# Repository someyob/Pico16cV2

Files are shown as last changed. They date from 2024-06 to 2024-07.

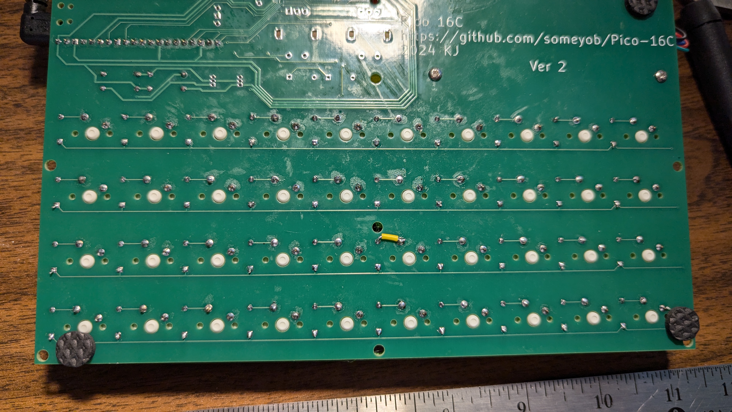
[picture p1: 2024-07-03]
pictures/bodge installed.jpg

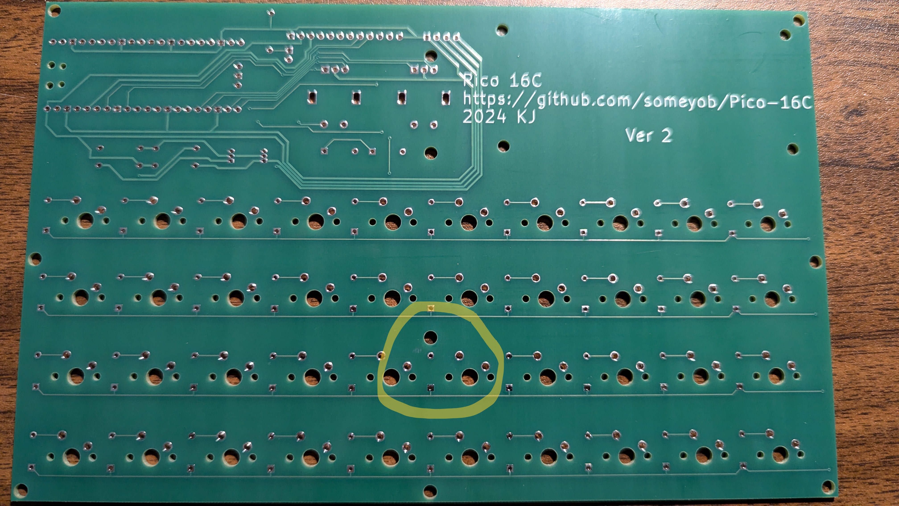
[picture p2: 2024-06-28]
pictures/bottom w. bodge.jpg

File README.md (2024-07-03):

# Pico16cV2

I've always wanted an HP 16C calculator, the gold standard for early programmers.  In those years, I was too poor, needed to focus on Scientific Calculators in university.  These days, prices are crazy on the used market.

While newer incarnations existed, (e.g. SwissMicro https://www.swissmicros.com/product/dm16l) looked great, they did't scratch my other itches, which were to play with microcontrollers and learn a new language (python).  The primary use for the thing will be (and is now) as a tool to help with the design and assembly language programming of a 6502-based computer.  This computer is based off of the Ben Eater instructional videos, which I highly recommend.

The prototype was done with cheap aliexpress parts and prototoboard, and can be seen here:  https://github.com/someyob/Pico-16C

Because I wasn't happy with the keypads (primarily), and hoped to make a more professional version, I did up a citcuit in KiCAD and sent away to have the PCBs done at PCBway.  (the build was sponsored by PCBway, and my thoughts on the product and the company will be posted on my Hackaday.io page).

The original prototype and version 2 getting assembled:



I used brown keyswitches with transparent 2-piece keycaps to create the keyboard, a standard i2c 1602 lcd display (2 lines of 16 characters), and a Raspberry Pi Pico.  The coding is done in CircuitPython.  The result is much bigger than a real 16C, but that wasn't a huge impediment for me.  The biggest challenge, aside from coding, was to make the keycaps look good.  I think it's an improvement over the prototype.

The fully assembled v2 is shown here:

v2 pic 1
v2 pic 2

At this point, lots of extra functionality still has to go in here, but it does the basic stuff, and in the same fashion as the true 16C (using RPN).

You may note that there's some unpopulated components on the PCB.  In order to take advantage of the space, and create other optional capabilities, I added two rotary encoders and included them (each includes a push-button) in the keypad matrix.  This way, I can use the same pcb as a basis for a macro keyboard.  There's also breakouts of the unused Pi Pico GPIO as well as a spot for an LED, should it find a use.

More notes on the build and the software to come.

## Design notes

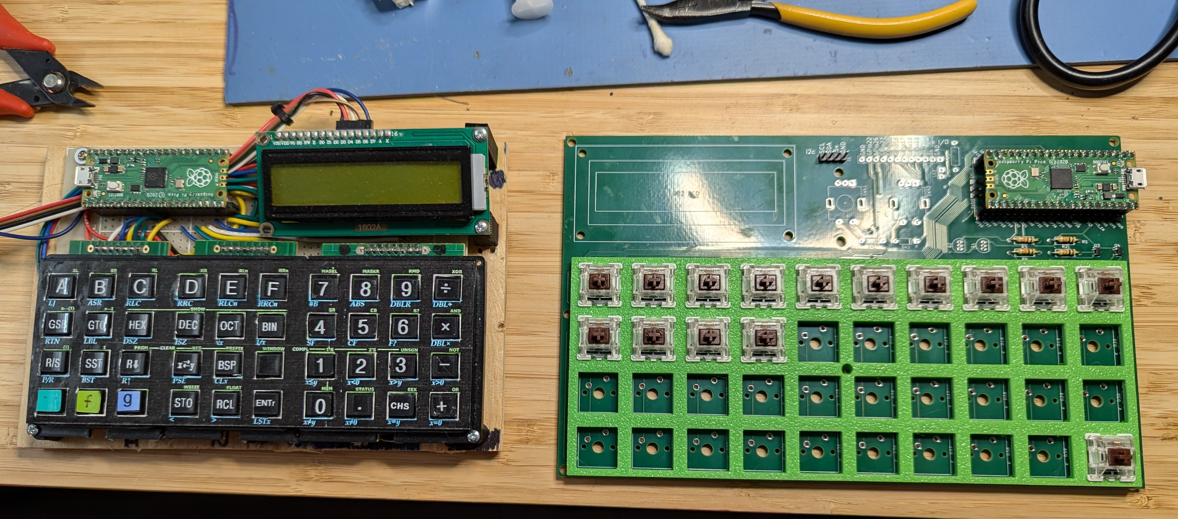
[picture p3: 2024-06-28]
pictures/prototype and v2.jpg

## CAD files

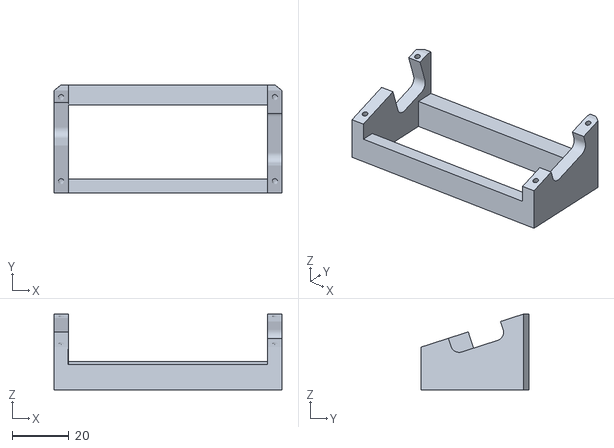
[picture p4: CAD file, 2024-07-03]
3dparts/displaybracket.stl
80.0 x 38.0 x 26.6

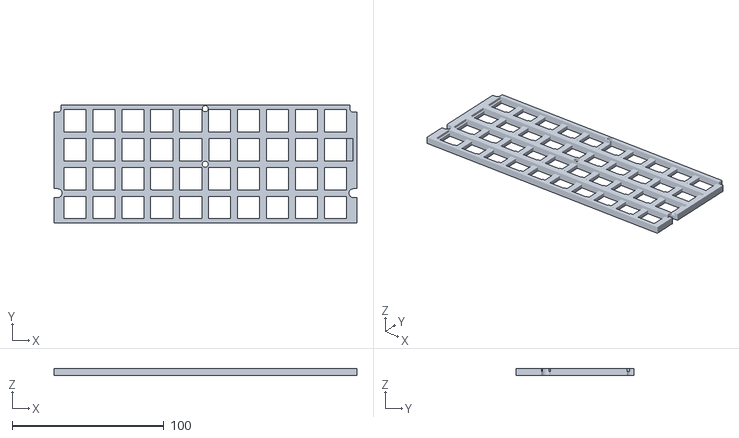
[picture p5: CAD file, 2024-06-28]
3dparts/keypad.stl
199.9 x 77.6 x 4.80

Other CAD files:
3dparts/displaybracket.skp
3dparts/keypad.skp

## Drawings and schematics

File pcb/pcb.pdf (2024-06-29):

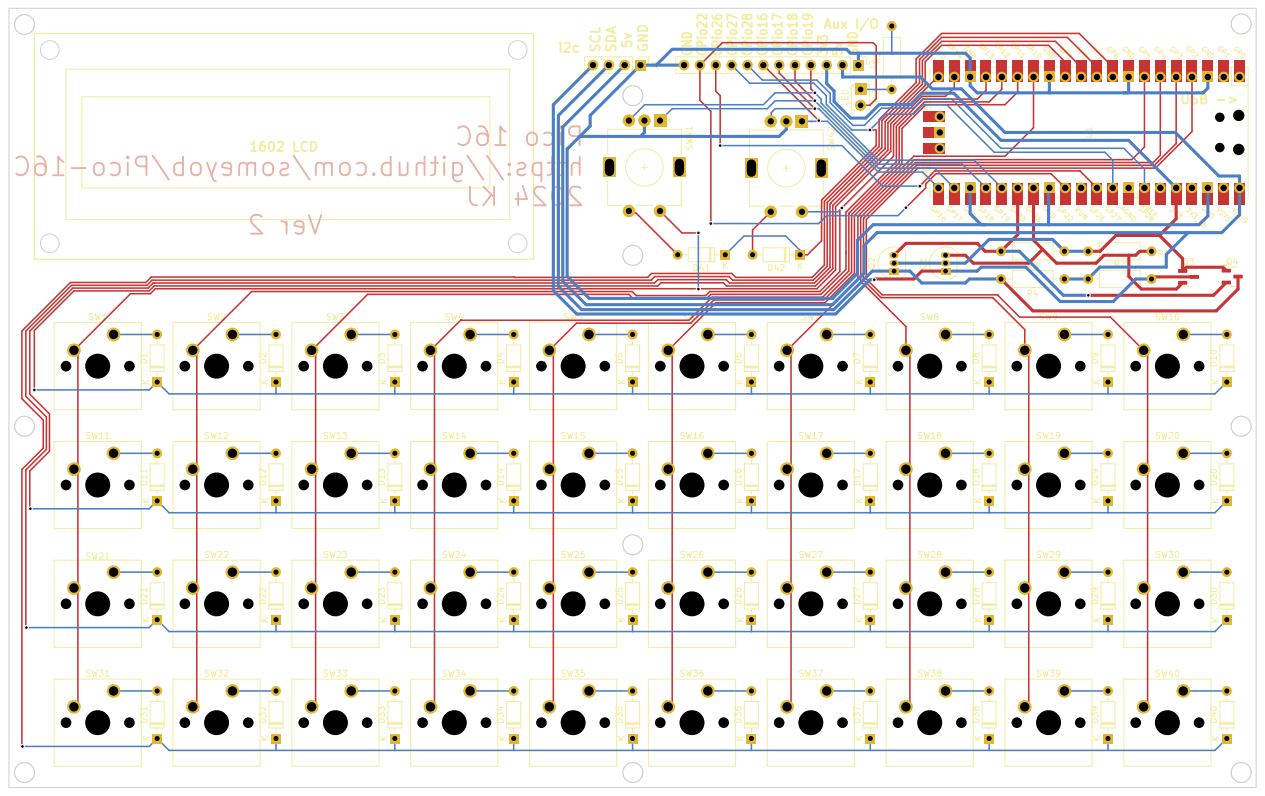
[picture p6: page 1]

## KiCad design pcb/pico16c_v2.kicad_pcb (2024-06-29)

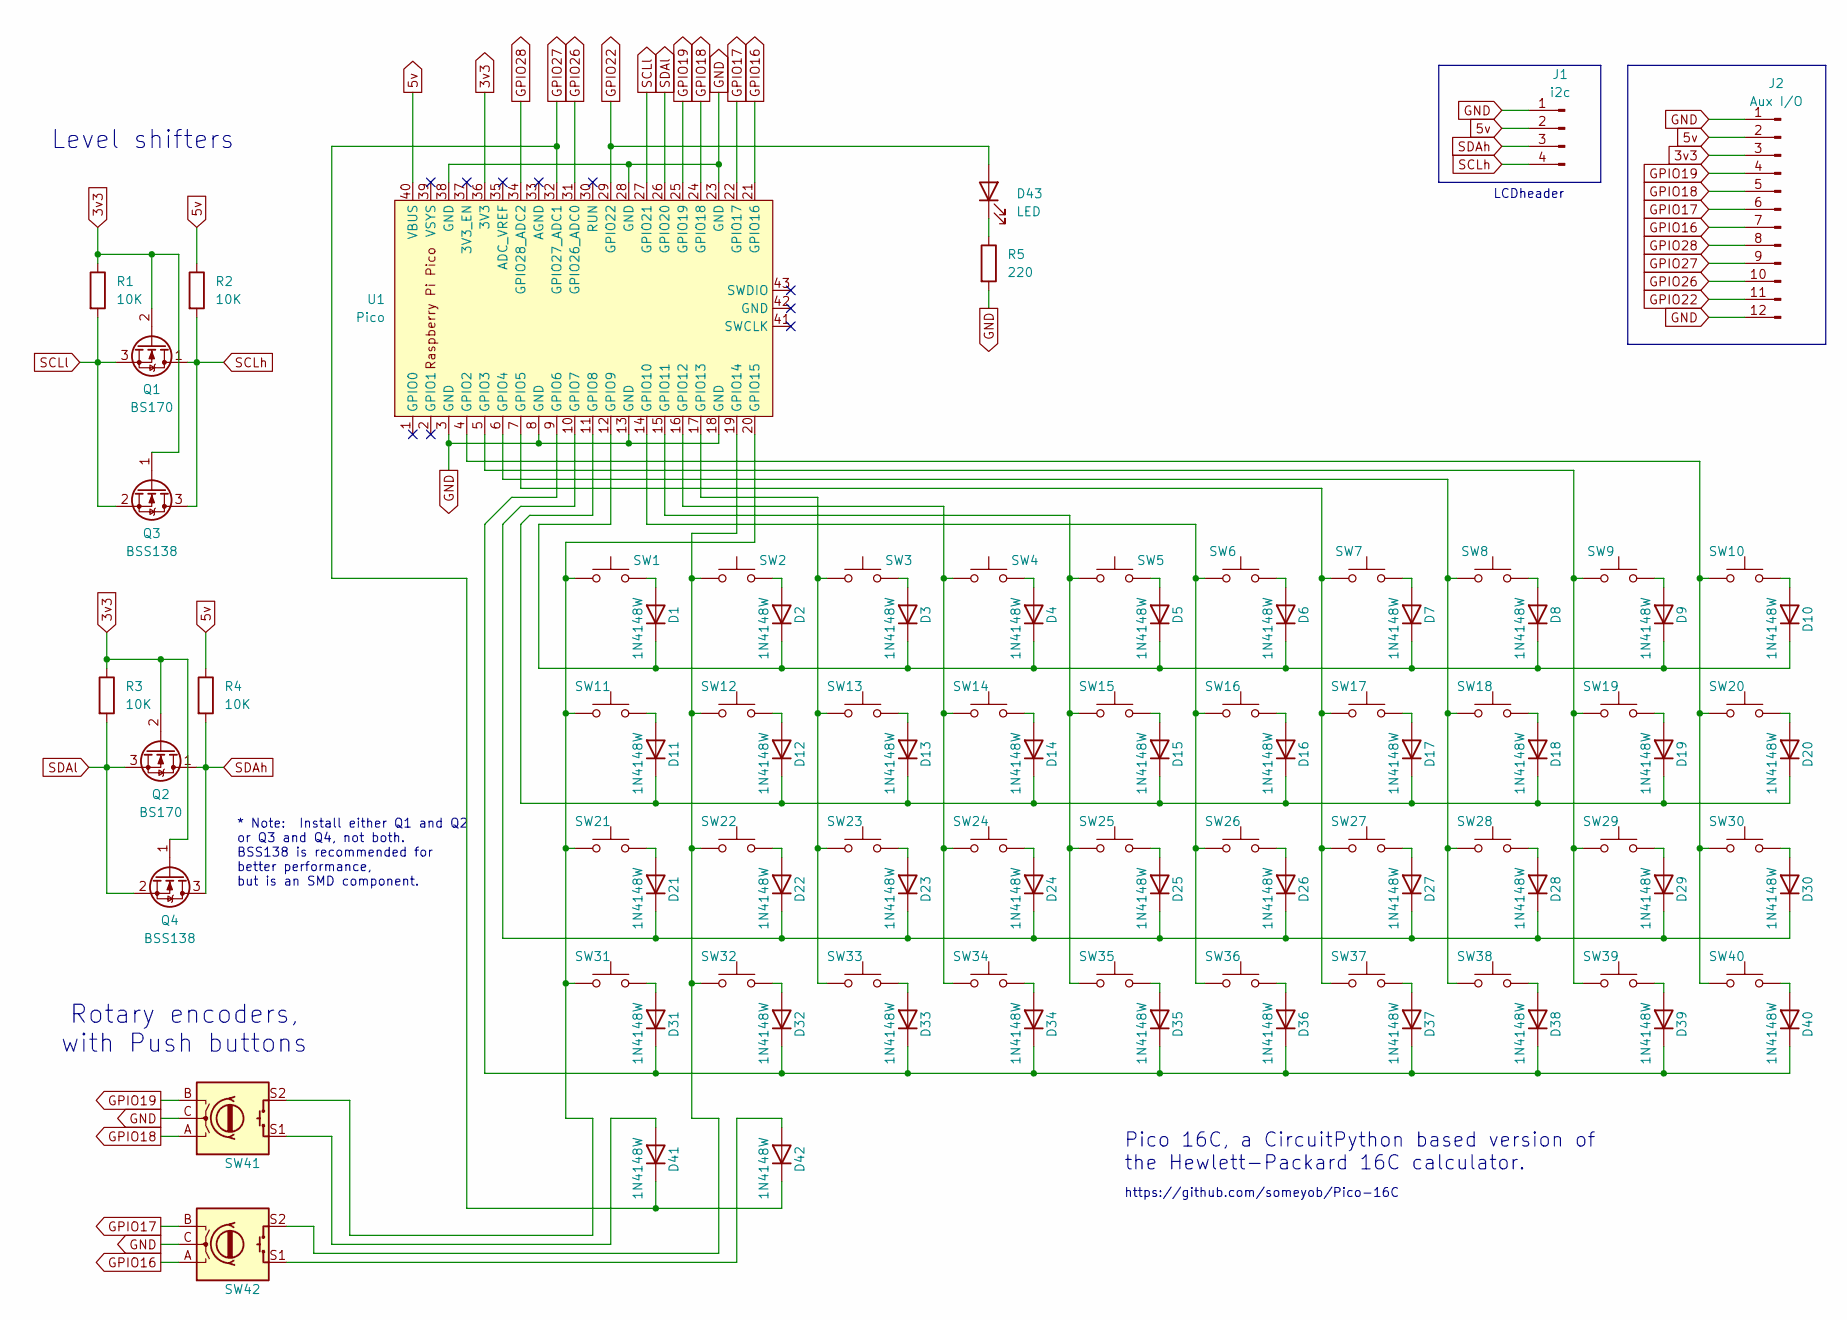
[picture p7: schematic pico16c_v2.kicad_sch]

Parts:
D1, D2, D3, D4, D5, D6, D7, D8, D9, D10, D11, D12, D13, D14, D15, D16, D17, D18, D19, D20, D21, D22, D23, D24, D25, D26, D27, D28, D29, D30, D31, D32, D33, D34, D35, D36, D37, D38, D39, D40, D41, D42: 1N4148W; D_DO-35_SOD27_P7.62mm_Horizontal
D43: LED; LED_D2.0mm_W4.0mm_H2.8mm_FlatTop
J1: i2c; PinHeader_1x04_P2.54mm_Vertical
J2: Aux I/O; PinHeader_1x12_P2.54mm_Vertical
Q1, Q2: BS170; TO-92_Inline
Q3, Q4: BSS138; SOT-23
R1, R2, R3, R4: 10K; R_Axial_DIN0207_L6.3mm_D2.5mm_P10.16mm_Horizontal
R5: 220; R_Axial_DIN0207_L6.3mm_D2.5mm_P10.16mm_Horizontal
SW1, SW2, SW3, SW4, SW5, SW6, SW7, SW8, SW9, SW10, SW11, SW12, SW13, SW14, SW15, SW16, SW17, SW18, SW19, SW20, SW21, SW22, SW23, SW24, SW25, SW26, SW27, SW28, SW29, SW30, SW31, SW32, SW33, SW34, SW35, SW36, SW37, SW38, SW39, SW40: SW_Push; SW_Cherry_MX_1.00u_PCB
SW41, SW42: Encoder_Switch; RotaryEncoder_Alps_EC11E-Switch_Vertical_H20mm
U1: Pico; RPi_Pico_SMD_TH

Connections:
3v3: J2.3, Q1.2 (G), Q2.2 (G), Q3.1 (G), Q4.1 (G), R1.1, R3.1, U1.36 (3V3)
5v: J1.2, J2.2, R2.1, R4.1, U1.40 (VBUS)
GND: J1.1, J2.1, J2.12, R5.2, SW41.C, SW42.C, U1.3 (GND), U1.8 (GND), U1.13 (GND), U1.18 (GND), U1.23 (GND), U1.28 (GND), U1.38 (GND)
GPIO16: J2.7, SW42.A, U1.21 (GPIO16)
GPIO17: J2.6, SW42.B, U1.22 (GPIO17)
GPIO18: J2.5, SW41.A, U1.24 (GPIO18)
GPIO19: J2.4, SW41.B, U1.25 (GPIO19)
GPIO22: D43.2 (A), J2.11, U1.29 (GPIO22)
GPIO26: J2.10, U1.31 (GPIO26_ADC0)
GPIO27: D41.1 (K), D42.1 (K), J2.9, U1.32 (GPIO27_ADC1)
GPIO28: J2.8, U1.34 (GPIO28_ADC2)
unnamed: D1.2 (A), SW1.1
unnamed: D1.1 (K), D2.1 (K), D3.1 (K), D4.1 (K), D5.1 (K), D6.1 (K), D7.1 (K), D8.1 (K), D9.1 (K), D10.1 (K), U1.12 (GPIO9)
unnamed: D2.2 (A), SW2.1
unnamed: D3.2 (A), SW3.1
unnamed: D4.2 (A), SW4.1
unnamed: D5.2 (A), SW5.1
unnamed: D6.2 (A), SW6.1
unnamed: D7.2 (A), SW7.1
unnamed: D8.2 (A), SW8.1
unnamed: D9.2 (A), SW9.1
unnamed: D10.2 (A), SW10.1
unnamed: D11.2 (A), SW11.1
unnamed: D11.1 (K), D12.1 (K), D13.1 (K), D14.1 (K), D15.1 (K), D16.1 (K), D17.1 (K), D18.1 (K), D19.1 (K), D20.1 (K), U1.11 (GPIO8)
unnamed: D12.2 (A), SW12.1
unnamed: D13.2 (A), SW13.1
unnamed: D14.2 (A), SW14.1
unnamed: D15.2 (A), SW15.1
unnamed: D16.2 (A), SW16.1
unnamed: D17.2 (A), SW17.1
unnamed: D18.2 (A), SW18.1
unnamed: D19.2 (A), SW19.1
unnamed: D20.2 (A), SW20.1
unnamed: D21.2 (A), SW21.1
unnamed: D21.1 (K), D22.1 (K), D23.1 (K), D24.1 (K), D25.1 (K), D26.1 (K), D27.1 (K), D28.1 (K), D29.1 (K), D30.1 (K), U1.10 (GPIO7)
unnamed: D22.2 (A), SW22.1
unnamed: D23.2 (A), SW23.1
unnamed: D24.2 (A), SW24.1
unnamed: D25.2 (A), SW25.1
unnamed: D26.2 (A), SW26.1
unnamed: D27.2 (A), SW27.1
unnamed: D28.2 (A), SW28.1
unnamed: D29.2 (A), SW29.1
unnamed: D30.2 (A), SW30.1
unnamed: D31.2 (A), SW31.1
unnamed: D31.1 (K), D32.1 (K), D33.1 (K), D34.1 (K), D35.1 (K), D36.1 (K), D37.1 (K), D38.1 (K), D39.1 (K), D40.1 (K), U1.9 (GPIO6)
unnamed: D32.2 (A), SW32.1
unnamed: D33.2 (A), SW33.1
unnamed: D34.2 (A), SW34.1
unnamed: D35.2 (A), SW35.1
unnamed: D36.2 (A), SW36.1
unnamed: D37.2 (A), SW37.1
unnamed: D38.2 (A), SW38.1
unnamed: D39.2 (A), SW39.1
unnamed: D40.2 (A), SW40.1
unnamed: D41.2 (A), SW41.S1
unnamed: D42.2 (A), SW42.S1
unnamed: D43.1 (K), R5.1
unnamed: SW10.2, SW20.2, SW30.2, SW40.2, U1.4 (GPIO2)
unnamed: SW9.2, SW19.2, SW29.2, SW39.2, U1.5 (GPIO3)
unnamed: SW8.2, SW18.2, SW28.2, SW38.2, U1.6 (GPIO4)
unnamed: SW7.2, SW17.2, SW27.2, SW37.2, U1.7 (GPIO5)
unnamed: SW6.2, SW16.2, SW26.2, SW36.2, U1.14 (GPIO10)
unnamed: SW5.2, SW15.2, SW25.2, SW35.2, U1.15 (GPIO11)
unnamed: SW4.2, SW14.2, SW24.2, SW34.2, U1.16 (GPIO12)
unnamed: SW3.2, SW13.2, SW23.2, SW33.2, U1.17 (GPIO13)
unnamed: SW2.2, SW12.2, SW22.2, SW32.2, SW42.S2, U1.19 (GPIO14)
unnamed: SW1.2, SW11.2, SW21.2, SW31.2, SW41.S2, U1.20 (GPIO15)
SCLh: J1.4, Q1.1 (D), Q3.3 (D), R2.2
SCLl: Q1.3 (S), Q3.2 (S), R1.2, U1.27 (GPIO21)
SDAh: J1.3, Q2.1 (D), Q4.3 (D), R4.2
SDAl: Q2.3 (S), Q4.2 (S), R3.2, U1.26 (GPIO20)

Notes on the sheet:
Pico 16C, a CircuitPython based version of the Hewlett-Packard 16C calculator.
https://github.com/someyob/Pico-16C
LCDheader
* Note: Install either Q1 and Q2 or Q3 and Q4, not both. BSS138 is recommended for better performance, but is an SMD component.
Rotary encoders, with Push buttons
Level shifters

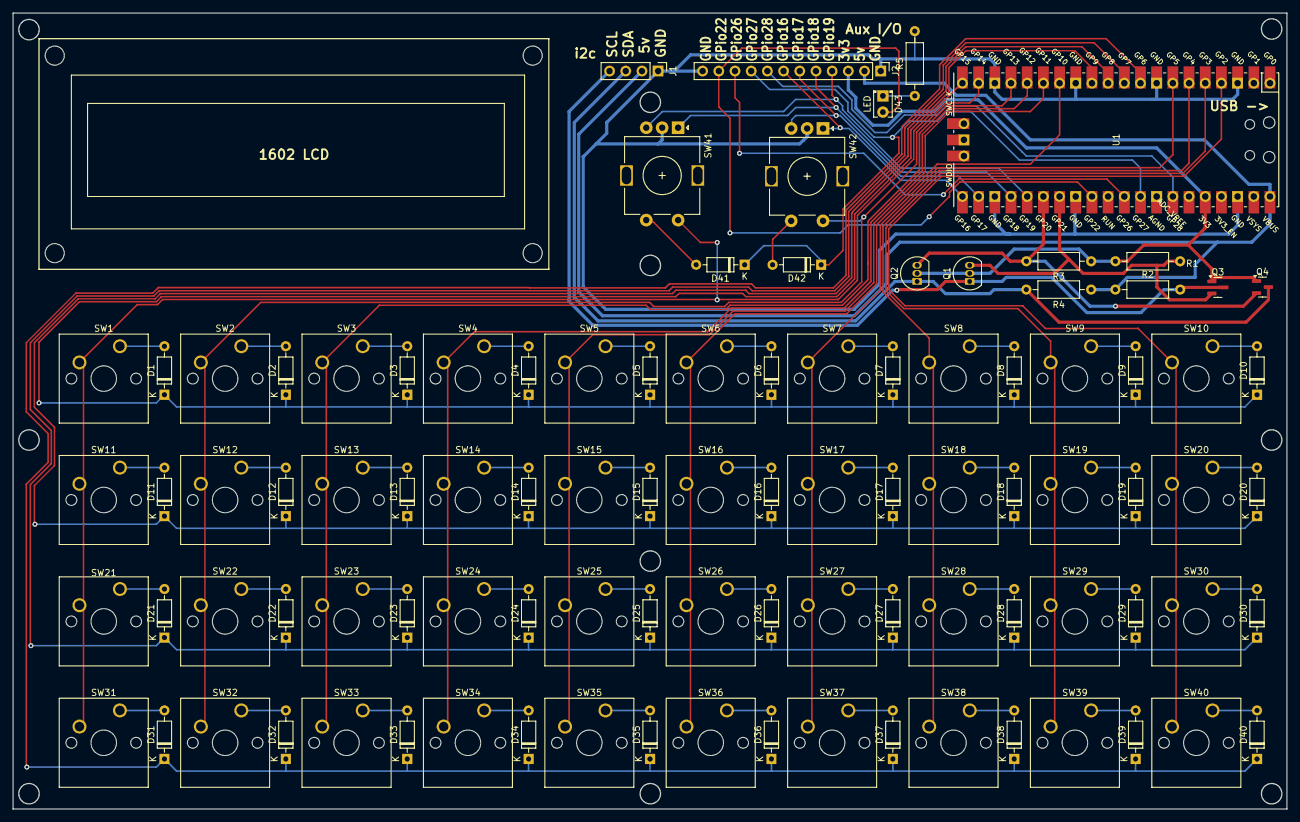
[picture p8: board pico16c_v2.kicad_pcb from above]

Board: 2 copper layers, 199.9 x 124.9 mm, 97 parts (0 on the bottom side), 72 nets.

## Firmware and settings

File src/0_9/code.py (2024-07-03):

# Use
# https://learn.adafruit.com/keep-your-circuitpython-libraries-on-devices-up-to-date-with-circup/usage
# 'circup' to manage packages on this device
# eg 'circup install adafruit_debouncer'

import time
import board
import busio
from time import sleep, monotonic
from circuitpython_i2c_lcd import I2cLcd
from PICO_16C_keypad import *

from digitalio import DigitalInOut, Pull

import keypad

version_string = "Pico 16C v0.9"
release_string = "29 Jun 2024   KJ"

#### Display init
i2c = busio.I2C(board.GP21, board.GP20)   # SCL, SDA
# circuitpython seems to require locking the i2c bus
while i2c.try_lock():
    pass

DEFAULT_I2C_ADDR = 0x27
lcd = I2cLcd(i2c, DEFAULT_I2C_ADDR, 2, 16)


def splash():
    lcd.backlight_on()
    print(version_string)
    print(release_string)
    lcd.clear()
    lcd.putstr(version_string)
    lcd.move_to(0, 1)
    lcd.putstr(release_string)
    sleep(3)
    return

base_char = [ 'b', 'o', 'd', 'h', ' ' ]   # displays nothing when in float
shift_char = [' ', 'f', 'g', ' ']
float_str = 'float'
arrow_overflow_right = [ 0x00, 0x08, 0x0C, 0x0E, 0x0C, 0x08, 0x00, 0x00]
arrow_overflow_left = [ 0x00, 0x02, 0x06, 0x0E, 0x06, 0x02, 0x00, 0x00]
overflow_right_flag = 1
overflow_left_flag = 2

def display_Xreg(calc):
    # lcd.clear()
    lcd.move_to(0,0)
    OFlow = 0
    if calc.base == BASE_STATE_BIN:
        calc.Xstr = f'{calc.Xreg:>16b}'
    elif calc.base == BASE_STATE_OCT:
        calc.Xstr = f'{calc.Xreg:>16o}'
    elif calc.base == BASE_STATE_DEC:
        calc.Xstr = f'{calc.Xreg:>16}'
    elif calc.base == BASE_STATE_HEX:
        calc.Xstr = f'{calc.Xreg:>16x}'.upper()
    elif calc.base == BASE_STATE_FLOAT:
        num_places = calc.decimalPlaces
        if calc.entry_in_progress:
            if calc.decimals_entered == 0:
                num_places = 1
            else:
                num_places = calc.decimals_entered
        if calc.ExponentMode or calc.ExponentEntry:
            calc.Xstr = f'{calc.Xreg:.{num_places}e}'
        else:
            calc.Xstr = f'{calc.Xreg:.{num_places}f}'    # show what user is entering, truncate later
    OFlow = 0
    if len(calc.Xstr) > 16:
        if calc.strindex == 0:
            calc.Xstr = calc.Xstr[-16:]
            OFlow += overflow_left_flag
        else:
            calc.Xstr = calc.Xstr[-16-calc.strindex:-calc.strindex]
            OFlow = overflow_right_flag + overflow_left_flag
            if len(calc.Xstr) != 16:
                OFlow -= overflow_left_flag
            while len(calc.Xstr) < 16:
                calc.Xstr = ' ' + calc.Xstr
    # print(strindex, ">", Xstr, "<")
    lcd.putstr(calc.Xstr)
    return OFlow

    
def print_calc_modes(calc, OFlow):  
    lcd.move_to(15, 1)
    lcd.putchar(base_char[calc.base])

    if calc.shift == SHIFT_STATE_FLOAT:
        lcd.move_to(0, 1)
        lcd.putstr('float (0-9,.)')
    else:
        lcd.move_to(1, 1)
        lcd.putchar(shift_char[calc.shift])
    
    if calc.ExponentEntry:
        lcd.move_to(3, 1)
        lcd.putstr('exp')
            
    cust_char = base_char[calc.base]    # ????
    if OFlow & overflow_left_flag: 
        lcd.move_to(13, 1)
        lcd.custom_char(0, arrow_overflow_left)
        lcd.putchar(chr(0))
    
    if OFlow & overflow_right_flag:  
        lcd.move_to(14, 1)
        lcd.custom_char(1, arrow_overflow_right)
        lcd.putchar(chr(1))
        
    if calc.CarryBit:
        lcd.move_to(11, 1)
        lcd.putchar('c')
    return
    
def display_status(calc):
    lcd.clear()
    lcd.move_to(3, 0)
    lcd.putstr(f'{calc.complement}-{calc.wordSize}-{calc.flagIndicators:0{4}b}')
    return
    
def refresh_screen(calc):
    lcd.clear()
    # time.sleep(0.1)
    
    # OFlow = display_Xreg(calc.Xreg, calc.base, calc.strindex, calc.decimalPlaces, calc.entry_in_progress)
    OFlow = display_Xreg(calc)
    print_calc_modes(calc, OFlow)
    return

def print_status(calc):
    if calc.base == BASE_STATE_FLOAT:
        print("\nT  %.9f" % calc.Treg)
        print("Z  %.9f" % calc.Zreg)
        print("Y  %.9f" % calc.Yreg)
        print("X  %.9f" % calc.Xreg)
        print("LX %.9f" % calc.LastX)
    else:
        print("\nT  ", calc.Treg)
        print("Z  ", calc.Zreg)
        print("Y  ", calc.Yreg)
        print("X  ", calc.Xreg)
        print("LX ", calc.LastX)
    print("Base (", base_char[calc.base], "),  Shift (", shift_char[calc.shift], ")")
    print(">", calc.Xbuff, "< input buffer", calc.decimals_entered)
    # print("strindex = ", calc.strindex)

    # gc.collect()
    #start_mem = gc.mem_free()
    #print( "Point 1 Available memory: {} bytes".format(start_mem) ) 
    return

def paste_Xreg(calc):
    if calc.base == BASE_STATE_BIN:
        Xstr = f'{calc.Xreg:b}'
    elif calc.base == BASE_STATE_OCT:
        Xstr = f'{calc.Xreg:o}'
    elif calc.base == BASE_STATE_DEC:
        Xstr = f'{calc.Xreg}'
    elif calc.base == BASE_STATE_HEX:
        Xstr = f'{calc.Xreg:x}'.upper()
    elif calc.base == BASE_STATE_FLOAT:
        Xstr = f'{calc.Xreg:.{3}f}' 
    layout.write(Xstr)
    return 

def main_loop():

    splash()
    lcd.clear()
    
    calculator = Calculator()
    refresh_screen(calculator)
    print_status(calculator)   

    while True:
        if calculator.check_timeout() and calculator.calcstate == STATE_ON:
            lcd.backlight_off()
            # print("Timed out")
            calculator.wait_keypress()
            lcd.backlight_on()
             
        calculator.check_keypress()
        
        if (calculator.key >= 0):
            key_event = getattr(calculator, key_functions[calculator.key])
            key_event(calculator.key)             
            if calculator.calcstate == STATE_OFF:
                lcd.clear()
                lcd.backlight_off()
            else:
                lcd.backlight_on()
                if calculator.macroState == MACRO_STATE_1:
                    paste_Xreg(calculator)  # paste Xbuff into whatever app is open
                    calculator.macroState = MACRO_STATE_OFF
                if calculator.showSplash:
                    splash()
                    calculator.wait_keypress()
                    calculator.showSplash = False
                if calculator.showStatus:
                    display_status(calculator)
                    calculator.wait_keypress()
                    calculator.showStatus = False
                      
                refresh_screen(calculator)
                print_status(calculator)
       
    return
    

#if __name__ == "__main__":
main_loop()

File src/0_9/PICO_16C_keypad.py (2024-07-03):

import board
import keypad
import time

TIMEOUT_INTERVAL = 300  # 5 minutes

#  KEYPAD CONSTANTS
# shift f + 40
# shift g + 80
KP_DECIMAL_PT = 32
KP_STATUS = KP_DECIMAL_PT + 40
KP_NE_ZERO = KP_DECIMAL_PT + 80

KP_ZERO = 33
KP_MEM = KP_ZERO + 40
KP_NE_Y = KP_ZERO + 80

KP_ONE = 23
KP_ONES_COMP = KP_ONE + 40
KP_LE_Y = KP_ONE + 80

KP_TWO = 22
KP_TWOS_COMP = KP_TWO + 40
KP_LT_ZERO = KP_TWO + 80

KP_THREE = 21
KP_UNSGN = KP_THREE + 40
KP_GT_Y = KP_THREE + 80

KP_FOUR = 13
KP_SB = KP_FOUR + 40
KP_SF = KP_FOUR + 80

KP_FIVE = 12
KP_CB = KP_FIVE + 40
KP_CF = KP_FIVE + 80

KP_SIX = 11
KP_BQ = KP_SIX + 40
KP_FQ = KP_SIX + 80

KP_SEVEN = 3
KP_MASKL = KP_SEVEN + 40
KP_NUM_B = KP_SEVEN + 80

KP_EIGHT = 2
KP_MASKR = KP_EIGHT + 40
KP_ABS = KP_EIGHT + 80

KP_NINE = 1
KP_RMD = KP_NINE + 40
KP_DBLR = KP_NINE + 80

KP_A = 9
KP_SL = KP_A + 40
KP_LJ = KP_A + 80

KP_B = 8
KP_SR = KP_B + 40
KP_ASR = KP_B + 80

KP_C = 7
KP_RL = KP_C + 40
KP_RLC = KP_C + 80

KP_D = 6
KP_RR = KP_D + 40
KP_RRC = KP_D + 80

KP_E = 5
KP_RLn = KP_E + 40
KP_RLCn = KP_E + 80

KP_F = 4
KP_RRn = KP_F + 40
KP_RRCn = KP_F + 80

# ARITHMETIC Operators
KP_ADD = 30
KP_OR = KP_ADD + 40
KP_EQ_ZERO = KP_ADD + 80

KP_SUBTRACT = 20
KP_NOT = KP_SUBTRACT + 40
KP_GT_ZERO = KP_SUBTRACT + 80

KP_MULTIPLY = 10
KP_AND = KP_MULTIPLY + 40
KP_DBLMULT = KP_MULTIPLY + 80

KP_DIVIDE = 0
KP_XOR = KP_DIVIDE + 40
KP_DBLDIV = KP_DIVIDE + 80

KP_CHS = 31
KP_EEX = KP_CHS + 40
KP_EQ_Y = KP_CHS + 80

# Enter
KP_ENTER = 34
KP_FMACRO = KP_ENTER + 40
KP_LST_X = KP_ENTER + 80

KP_ENTER2 = 24
KP_WINDOW = KP_ENTER2 + 40
KP_GMACRO = KP_ENTER2 + 80

KP_BIN = 14
KP_SHOW_BIN = KP_BIN + 40
KP_ONE_OVER_X = KP_BIN + 80

KP_OCT = 15
KP_SHOW_OCT = KP_OCT + 40
KP_SQRT_X = KP_OCT + 80

KP_DEC = 16
KP_SHOW_DEC = KP_DEC + 40
KP_ISZ = KP_DEC + 80

KP_HEX = 17
KP_SHOW_HEX = KP_HEX + 40
KP_DSZ = KP_HEX + 80

KP_BSP = 25
KP_CLR_PREFIX = KP_BSP + 40
KP_CLx = KP_BSP + 80

KP_XY = 26
KP_CLR_REG = KP_XY + 40
KP_PSE = KP_XY + 80

KP_RDN = 27
KP_CLR_PGM = KP_RDN + 40
KP_RUP = KP_RDN + 80

KP_SST = 28
KP_I = KP_SST + 40
KP_BST = KP_SST + 80

KP_RS = 29
KP_I_BR = KP_RS + 40
KP_PR = KP_RS + 80

KP_GSB = 19
KP_XI_BR = KP_GSB + 40
KP_RTN = KP_GSB + 80

KP_GTO = 18
KP_XI = KP_GTO + 40
KP_LBL = KP_GTO + 80

KP_RCL = 35
KP_FLOAT = KP_RCL + 40
KP_DISP_R = KP_RCL + 80

KP_STO = 36
KP_WSIZE = KP_STO + 40
KP_DISP_L = KP_STO + 80

KP_SHIFT_F = 38
KP_SHIFT_G = 37

KP_ON = 39



##########################################################
# layout reversed, right to left

keys_char = [ '/',  '9',   '8',  '7',  'F',     'E',   'D',   'C',   'B',   'A',
              '*',  '6',   '5',  '4',  'BIN',   'OCT', 'DEC', 'HEX', 'GTO', 'GSB',
              '-',  '3',   '2',  '1',  'E2',    'BSP', 'XY',  'RD',  'SST', 'RS',
              '+',  'CHS', '.',  '0',  'ENTER', 'RCL', 'STO', 'g',   'f',   'ON']

key_functions = [ 'f_mathOp', 'f_digit', 'f_digit', 'f_digit', 'f_digit', 'f_digit', 'f_digit', 'f_digit', 'f_digit', 'f_digit',
                  'f_mathOp', 'f_digit', 'f_digit', 'f_digit', 'f_base',  'f_base',  'f_base',  'f_base',  'f_undef', 'f_undef',
                  'f_mathOp', 'f_digit', 'f_digit', 'f_digit', 'f_undef', 'f_BSP',   'f_XY',    'f_rolld', 'f_undef', 'f_undef',
                  'f_mathOp', 'f_CHS',   'f_digit', 'f_digit', 'f_ENTER', 'f_undef', 'f_undef', 'f_shift', 'f_shift', 'f_ON',
 # shift f:                 
                  'f_mathOp', 'f_undef', 'f_undef', 'f_undef', 'f_undef', 'f_undef', 'f_undef', 'f_undef', 'f_undef', 'f_undef',
                  'f_mathOp', 'f_undef', 'f_undef', 'f_undef', 'f_base',  'f_base',  'f_base',  'f_base',  'f_undef', 'f_undef',
                  'f_mathOp', 'f_compl', 'f_compl', 'f_compl', 'f_undef', 'f_undef', 'f_undef', 'f_undef', 'f_undef', 'f_undef',
                  'f_mathOp', 'f_digit', 'f_stat',  'f_undef', 'f_fmacr', 'f_float',  'f_undef', 'f_shift', 'f_shift', 'f_splsh',
 # shift g:                 
                  'f_undef', 'f_undef', 'f_undef', 'f_undef', 'f_undef', 'f_undef', 'f_undef', 'f_undef', 'f_undef', 'f_undef',
                  'f_undef', 'f_undef', 'f_undef', 'f_undef', 'f_undef', 'f_undef', 'f_undef', 'f_undef', 'f_undef', 'f_undef',
                  'f_undef', 'f_undef', 'f_undef', 'f_undef', 'f_gmacr', 'f_CLx',   'f_undef', 'f_rollu', 'f_undef', 'f_undef',
                  'f_undef', 'f_undef', 'f_undef', 'f_undef', 'f_LastX', 'f_pan_d', 'f_pan_d', 'f_shift', 'f_shift', 'f_splsh']

bin_num_keys = (KP_ZERO, KP_ONE)
oct_num_keys = (KP_ZERO, KP_ONE, KP_TWO, KP_THREE, KP_FOUR, KP_FIVE, KP_SIX, KP_SEVEN)
dec_num_keys = (KP_ZERO, KP_ONE, KP_TWO, KP_THREE, KP_FOUR, KP_FIVE, KP_SIX, KP_SEVEN, KP_EIGHT, KP_NINE)
hex_num_keys = (KP_ZERO, KP_ONE, KP_TWO, KP_THREE, KP_FOUR, KP_FIVE, KP_SIX, KP_SEVEN, KP_EIGHT, KP_NINE,
                    KP_A, KP_B, KP_C, KP_D, KP_E, KP_F)
float_num_keys = (KP_DECIMAL_PT, KP_ZERO, KP_ONE, KP_TWO, KP_THREE, KP_FOUR, KP_FIVE,
                          KP_SIX, KP_SEVEN, KP_EIGHT, KP_NINE, KP_EEX)
all_num_keys = (KP_DECIMAL_PT, KP_ZERO, KP_ONE, KP_TWO, KP_THREE, KP_FOUR, KP_FIVE,
                    KP_SIX, KP_SEVEN, KP_EIGHT, KP_NINE,
                    KP_A, KP_B, KP_C, KP_D, KP_E, KP_F)
operator_keys = (KP_ADD, KP_SUBTRACT, KP_MULTIPLY, KP_DIVIDE)  # +-x/
base_keys = (KP_BIN, KP_OCT, KP_DEC, KP_HEX, KP_FLOAT)
show_base_conversion_keys = (KP_SHOW_BIN, KP_SHOW_OCT, KP_SHOW_DEC, KP_SHOW_HEX)
window_value_keys = (KP_ZERO, KP_ONE, KP_TWO, KP_THREE, KP_FOUR, KP_FIVE, KP_SIX, KP_SEVEN)

STATE_OFF = 0
STATE_ON = 1

SHIFT_STATE_OFF = 0
SHIFT_STATE_F = 1
SHIFT_STATE_G = 2
SHIFT_STATE_FLOAT = 3

BASE_STATE_BIN   = 0
BASE_STATE_OCT   = 1
BASE_STATE_DEC   = 2
BASE_STATE_HEX   = 3
BASE_STATE_FLOAT = 4

MAX_WORD_SIZE = 128
MAX_DECIMAL_PLACES = 9

LEAD_ZERO_FLAG = 8
USER_FLAG_2 = 4
USER_FLAG_1 = 2
USER_FLAG_0 = 1

MACRO_STATE_OFF = 0
MACRO_STATE_1 = 1
MACRO_STATE_2 = 2
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

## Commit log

2024-07-03 Rename PXL_20240627_195622227.jpg to pico and diodes.jpg
2024-07-03 Update and rename pico and diodes.jpg to pico and diodes.jpg
2024-07-03 Rename v1 vs v2.jpg to prototype and v2.jpg
